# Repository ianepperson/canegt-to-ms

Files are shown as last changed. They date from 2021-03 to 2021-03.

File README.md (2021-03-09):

# canegt-to-ms
A simple device to translate CAN-EGT signals to Megasquirt (MS) CLT

## Why?

The [CAN-EGT device](https://thedubshop.com/can-egt/) is fantastic in that it reads and stabilizes head and exhaust temperatures and provides the data via CAN-Bus and a voltage output. Unfortunately, Megasquirt ignores this data and requires a separate "coolant" (CLT) analog input so it can know when the engine is warm. When you have an air-cooled engine, you'll need to simulate the coolant signal. The device described here will do just that.

## The Problem

The CAN-EGT provides a 0-5 volt output signal for each of its inputs.  Regardless of what is in the ini file, the output represents 0 to 1250 degrees celcius with 0 volts = 0 degrees C and 5 volts = 1250 degrees C. The device provides a nice, linear output. (The CHT should be at about 175 degrees C normally - 1250 C is past the melting point of aluminum!)

Megasquirt needs a variable resistance to ground, where a high resistance denotes a low temperature and a low resistance denotes a high temperature. The actual values are adjustable in Tuner Studio, but the low temperature must have a higher resistance than the high temperature. Another way of stating it is that higher temps are denoted with a higher current.

An analog circuit could be constructed to convert the 0-5 volts into the proper resistance to ground, but a tiny microprocessor is cheap and easier to implement. The Megasquirt input could be modified to remove the resister stack and then it could just read the 0-5 volts directly, but the Minisquirt board is difficult to modify.

## The Solution

A small, custom, cheap board that translates the CAN-EGT output to the Megasquirt CLT input. No Megasquirt or CAN-EGT modifications necessary.

### Hardware

The [Adafruit Trinket](https://www.adafruit.com/product/1501) is a $6 processor that is powered by a 5-16 volt input, has an input pin that reads precisely 0-5 volts on an input pin, can communicate with another simple chip via [SPI](https://en.wikipedia.org/wiki/Serial_Peripheral_Interface), and can provide that other chip with a stabilized 5 volts. Note that the [Trinket M0](https://www.adafruit.com/product/3500) might work and is radically easier to load code to, but it's only a 3 volt chip and other components would have to be added to translate the 0-5 volt into the 0-3 volt analog input.

[Trinket Pinouts](https://learn.adafruit.com/introducing-trinket/pinouts)

pin outs

The [MCP4151-103E/P](https://www.digikey.com/en/products/detail/microchip-technology/MCP4151-103E-P/1874217) is an SPI controlled 10k ohm potentiometer in a single chip. (I picked up a [5-pack on Amazon.com](https://www.amazon.com/gp/product/B00LVKK472) for $6, but it can be found at [other sources](https://www.mouser.com/ProductDetail/Microchip-Technology/MCP4151-103E-P?qs=hH%252BOa0VZEiCcBDYaXnd0Yg%3D%3D). Make sure you buy at least two - I melted my first one by reversing the polarity!)

[MCP4151 Pinouts]()

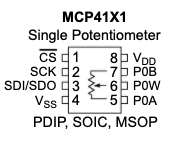
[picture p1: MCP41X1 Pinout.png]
pin outs


Vdd is 3 or 5 volts (2.7 to 5.5) and Vss is ground.

Since Megasquirt does not support a 0 ohm signal, add in a 470 ohm resister in series with the potentiometer. With the Arduino program in this folder, the CLT line will get a 470 ohm signal to represent 1250 degrees C and a 10470 ohm signal will represent 0 degrees C.

### Wiring

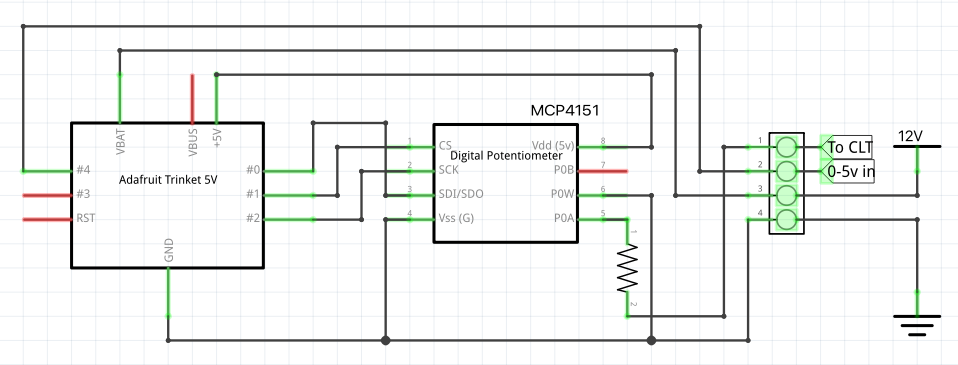
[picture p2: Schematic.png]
schematic


If you haven't done any electronics tinkering and don't already have a handy set of boards, headers and terminals, it's not a bad idea to pick up [a kit](https://www.amazon.com/s?k=pcb+board+kit).

You'll need 4 connections for external wiring.

 - Variable resistance output. Wire to a 470 ohm resister, then through to the MCP4151's P0A pin (5).
 - 0-5 volt sensor input. Wire to the Trinket's pin "#4" (2nd analog input).
 - Switched 12v input. Wire directly to the Trinket's "battery" input.
 - Ground. Wire to the Trinket's ground, and the MCP4151's Vss (4) and P0W (6) pins.

Note that the 0-5v sensor input uses the same pin as the Trinket's USB. This means that you cannot connect the USB port and the sensor input at the same time. In practice, this shouldn't be an issue, but if you need to reload code be sure and disconnect the sensor input.

The [Fritzing file](CAN-EGT-2-MS.fzz) (open with [Fritzing](https://fritzing.org/)) is available if you want to print a custom circuit board. (Click the "view raw" link to download).

### Software

Use the [Arduino IDE](https://www.arduino.cc/en/Main.Software) software to connect to the Trinket via USB and load the program. Make sure you've set it up for the [Adafruit boards](https://learn.adafruit.com/add-boards-arduino-v164/setup) in order to load to the Trinket. The file to load is here: [canegt-2-ms.ino](canegt-2-ms.ino), and download it with the [raw link](https://raw.githubusercontent.com/ianepperson/canegt-to-ms/main/canegt-2-ms.ino).

There's a lot of electrical noise in the engine compartment and the input bounces around quite a bit. Since the actual value changes very slowly, the code averages the last several readings (about 2 seconds worth) to the output in order to smooth out the signal.

## Finished product

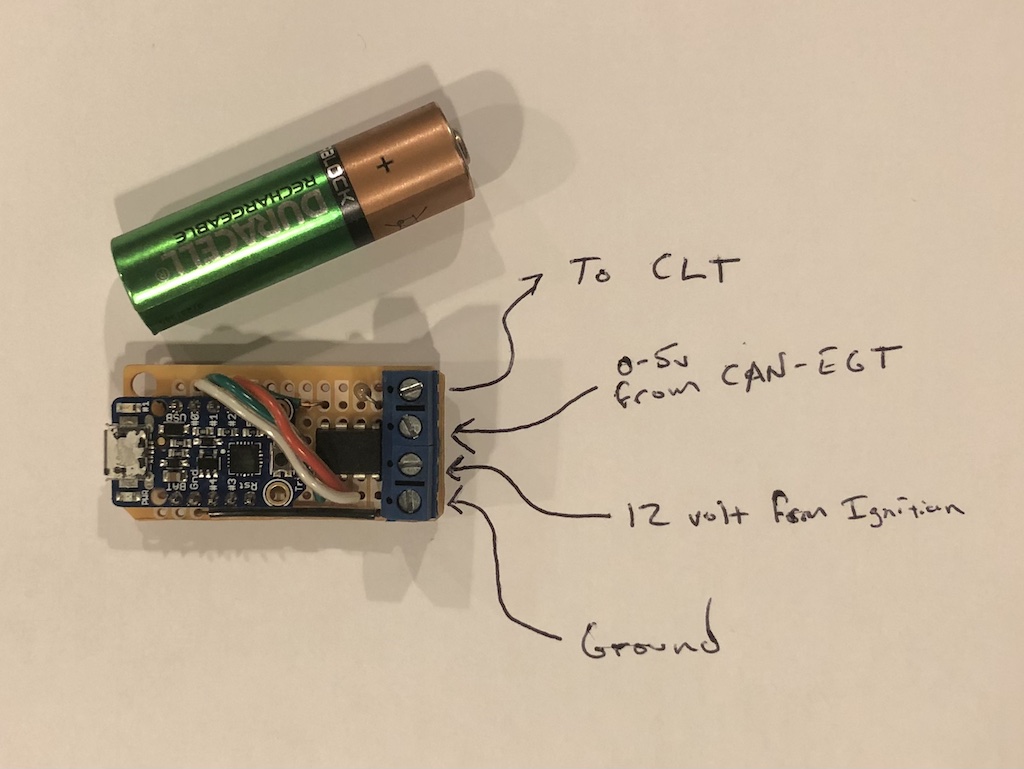
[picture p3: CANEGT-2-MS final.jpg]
Final product


(AA battery for scale)

It's small enough that I just slipped it into a heat-shrink tube to seal it up, and it's light enough that I just tuck it in with my car's wiring.

## TunerStudio

On the "Tools" top menu, select "Calibrate Thermister Tables..." and select the "Coolant Temperature Sensor". Set it to use a "3 Point Therm Generator", then fill in the table with the resister values that your little board is providing. You'll need to do a little math here and pick some linear values between 0 and 1270 degrees. The "Bias Resister Value" is the value of the onboard resister on the Megasquirt - likely 2490 ohms.

10000 ohms / 1250 degrees celcius = 8 ohms per degree

Resistance = (10000 - Temperature X 8) + 470 ohms

| Temperature | Resistance |
| --- | --- |
| 0.0 | 10470 |
| 175.0 | 9070 | 
| 350.0 | 7670 |

It's unlikely that you'll get values this precise - note that the circuit can't step any smaller than about 39 ohms (5 degrees C) - but this broad step is a good enough indicator for the warmup logic.

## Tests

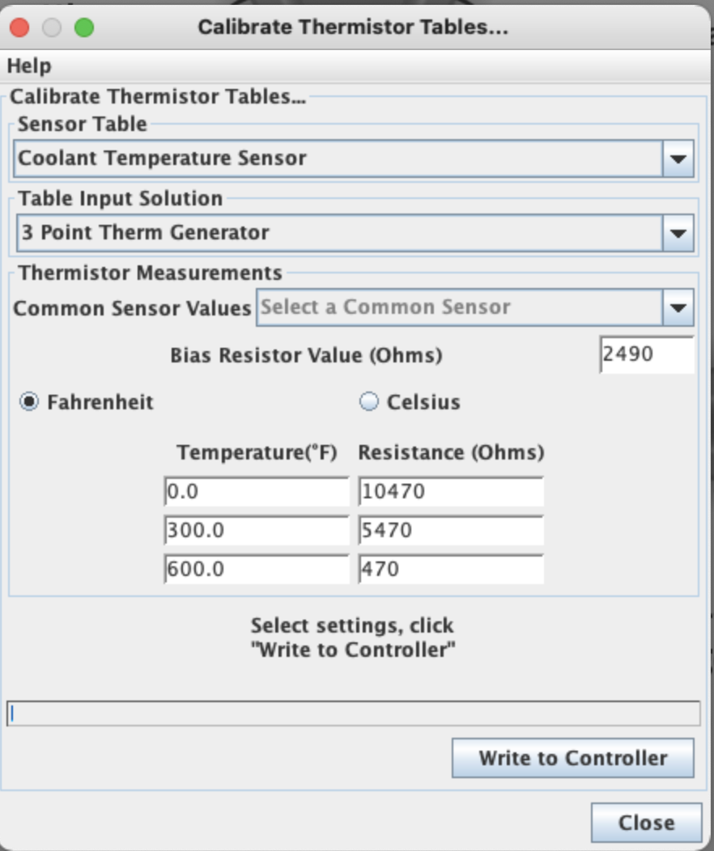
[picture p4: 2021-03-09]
TunerStudio Thermister Calibration.png

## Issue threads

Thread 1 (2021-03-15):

Make work with the Trinket M0

ianepperson, 2021-03-15:
It should be easier to load code to the M0 - which makes setting up the board easier for beginners. Could then also use MicroPython instead, which makes loading code as easy as copying a file to a thumb drive.

The 5v to 3v signal could be done with a simple voltage divider.
```
5v signal -- 10k resister -- 3.3v input -- 20k resister -- ground
```

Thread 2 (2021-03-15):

Increase accuracy

ianepperson, 2021-03-15:
The code currently represents 0 to 1250 degrees C, but the useful range is only up to about 300 degrees C. Narrowing the range (and adjusting the values in Tuner Studio accordingly) will make the conversion more accurate and less noisy.

Max resistance would still represent 0 C, but the min resistance could represent 300 C, which would allow the device to have a resolution close to 1.2 degree C (300 / 257) instead of the current 4.8 (1250 / 257).

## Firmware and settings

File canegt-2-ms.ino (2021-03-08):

      /*
  CAN-EGT to Mega/Micro squirt

  Capture the 0-5 volt output from the CAN-EGT which represents 0-1250 degrees C
  and convert it to a resistance via a digitial potentiometer.  This mimics
  what the MS is expecting for "coolant temperature" for air-cooled cars
  (old VWs!).
  
  To upload to your Gemma or Trinket:
  1) Select the proper board from the Tools->Board Menu
  2) Select USBtinyISP from the Tools->Programmer
  3) Plug in the Gemma/Trinket, make sure you see the green LED lit
  4) For windows, install the USBtiny drivers
  5) Press the button on the Gemma/Trinket - verify you see
     the red LED pulse. This means it is ready to receive data
  6) Click the upload button above within 10 seconds
*/
 
#define SPI_select 1  // SPI chip select for the digital pot.  (same pin as the built-in LED)
#define SPI_clock 2 // SPI clock
#define SPI_digout 0 // SPI serial output

#define EGT_in 2 // From the CAN-EGT's 0-5 volt out

#define Max_R 257 // Maximum resistance setting value.
#define Pot_address 0 // Which on-chip pot to use (0 if it's the only one)

#define numReadings 10 // How many readings to average out for smooth output

int sensor_value;

// The following variables are used to smooth the input reading
// It averages over the last "numReadings" input reads,
// which gives about an average of the last 2 seconds of reads.
int readings[numReadings];  // array to store the input reads
int readIndex = 0;        // which position in the array to update
int total = 0;            // running total of sensor readings
int average = 0;          // averaged output

// the setup routine runs once when you press reset:
void setup() {
  // initialize the digital pin as an output.
  pinMode(SPI_select, OUTPUT);
  pinMode(SPI_clock, OUTPUT);
  pinMode(SPI_digout, OUTPUT);
  //pinMode(EGT_in, INPUT);

  digitalWrite(SPI_select, HIGH);  // LOW triggers the start of comms
  digitalWrite(SPI_clock, LOW);  // Mode 0,0 in the digital pot docs

  read_sensor();

  // Initialize read array to the initial sensor value
  for (int ref = 0; ref < numReadings; ref++) {
    readings[ref] = sensor_value;
    total = total + sensor_value;
  }

}

void read_sensor() {
  // pause to allow the sensor to stabilize
  delay(10);
  sensor_value = analogRead(EGT_in);
  if (sensor_value > Max_R) {
    sensor_value = Max_R;
  }
}

void calculate_average() {
  // subtract the last reading:
  total = total - readings[readIndex];
  // read from the sensor:
  readings[readIndex] = sensor_value;
  // add the reading to the total:
  total = total + readings[readIndex];
  // advance to the next position in the array:
  readIndex = readIndex + 1;

  // if we're at the end of the array...
  if (readIndex >= numReadings) {
    // ...wrap around to the beginning:
    readIndex = 0;
  }

  // calculate the average:
  average = total / numReadings;
}

void send_r_value(int value) {
  // The command is made up of two bytes.
  int byte1 = 0;
  int byte2 = 0;
  
  // Set the clock to low for "mode 0,0"
  digitalWrite(SPI_clock, LOW);
  // Select the chip (also preps it for a message)
  digitalWrite(SPI_select, LOW);
  // Give the chip a moment to prepare
  delayMicroseconds(8);

  /*
   * Commands are sent in two bytes.
   * The first 4 bits indicate the address.  0000 is the first (or only) pot.
   * The next 2 bits are a command.  00 = set the value.
   * The next 10 bits are a value of 0 - 257
   */

  // Clamp at the max value
  if(value > Max_R) {
    value = Max_R;
  }

  // Prepare the data
  // first byte.  Mask the address over the first 4 bits
  byte1 = Pot_address << 4;
  // first byte.  Next two bits are write command - nothing to add for 00
  // first byte.  Next two bits are the upper two bits of the value
  byte1 = byte1 | ((value >> 8) & 0xFF);
  // second byte.  Remaining bits of the value
  byte2 = value & 0xFF;

  // Send the bytes
  shiftOut(SPI_digout, SPI_clock, MSBFIRST, byte1);
  shiftOut(SPI_digout, SPI_clock, MSBFIRST, byte2);

  // Give the chip a moment to think about things
  delayMicroseconds(8);
  
  // close down the connection, we're done
  digitalWrite(SPI_select, HIGH);
  digitalWrite(SPI_clock, LOW);
}

// the loop routine runs over and over again forever:
void loop() {
  read_sensor();
  calculate_average();
  send_r_value(average);
  
  delay(40);
  // clears the select and turns off the Trinket's LED.
  digitalWrite(SPI_select, LOW);
  delay(50);
  // sets the select and turns on the Trinket's LED.
  digitalWrite(SPI_select, HIGH);
}
    
